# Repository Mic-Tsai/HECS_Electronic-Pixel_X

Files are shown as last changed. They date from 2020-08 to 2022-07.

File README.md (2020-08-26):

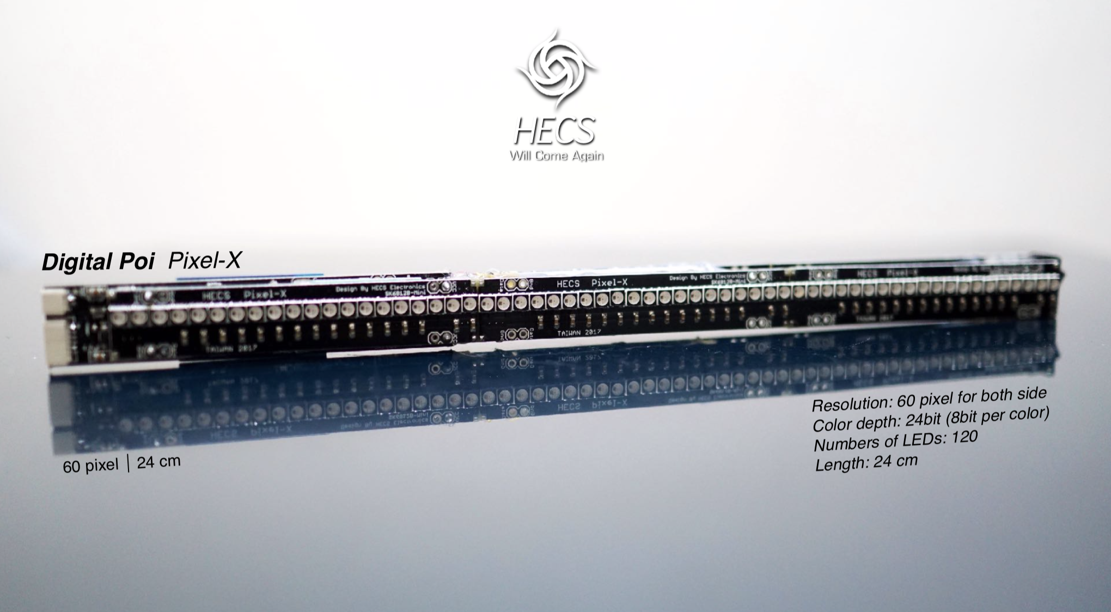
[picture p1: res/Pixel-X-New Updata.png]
*HECS Electronic | Pixel-X*


## HECS Electronic | Pixel-X
### Light Painting Equipment



2013 | HECS

We are a visual team of POI arty performers. Design and develop the light-painting equipment which contains picture & dynamic presentation. This was my college side project during 2013-2014 in KUAS (National Kaohsiung University of Applied Sciences, Taiwan).

- [Promotional Video](https://youtu.be/c2NhDoxItCM)

**2017 | Pixel-X**

  **Re-engineering hardware part, split the core as controller and display, purpose to minimum PCB after-assemble space. LEDs used the improved version SK6812B-3535 (package) from WS2812B-5050, got better heat radiating, the smaller dots will increase the image resolution.**

```
Arduino tool kit, and require the following material:
- MCU: ATmega328p
- Storage: SD card
- Display: SK6812B-3535
- Power source: Li-Po Battery
``` 

## 

### **About Mic**

Director of HECS, design light painting product that contains hardware layout and software programming.

- [Resume](https://drive.google.com/file/d/1NEWwNo3X4ogJMNzp6jpFyT0a6GPGhs7Q/view)
## 

### **About HECS**

Interesting how it work please refer for detail:

- [HECS ISSUU](https://issuu.com/56905554/docs/hecs_book)

- [HECS ISSUU moble device](https://issuu.com/56905554/docs/hecs-book_issuu)

- [HECS Electronics](https://drive.google.com/file/d/1tgr780FQ_Ib0JO3FdQn_M6LVbDeVmUmG/view?usp=sharing)
## 

### **About Hardware**

If you want to buy this board and are in Taiwan, please visit my shop: 

Will OPEN SOON:
* [HECS SHOP](https://www.)
* Contact me via mail (xbcke12345@gmail.com)
* If this project helping. Please generously support =)

   

## 
*HECS Electronic | Pixel-X*
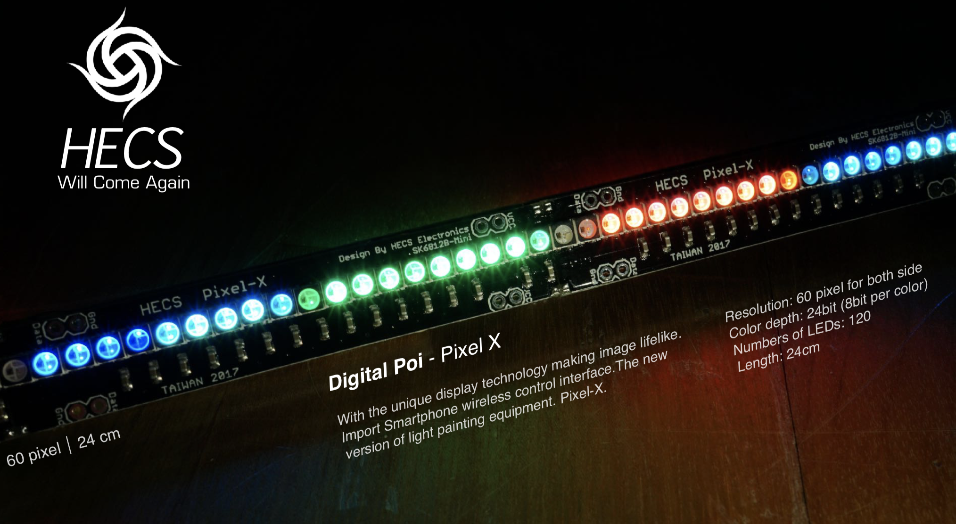
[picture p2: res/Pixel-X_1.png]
*HECS Electronic | Pixel-X*

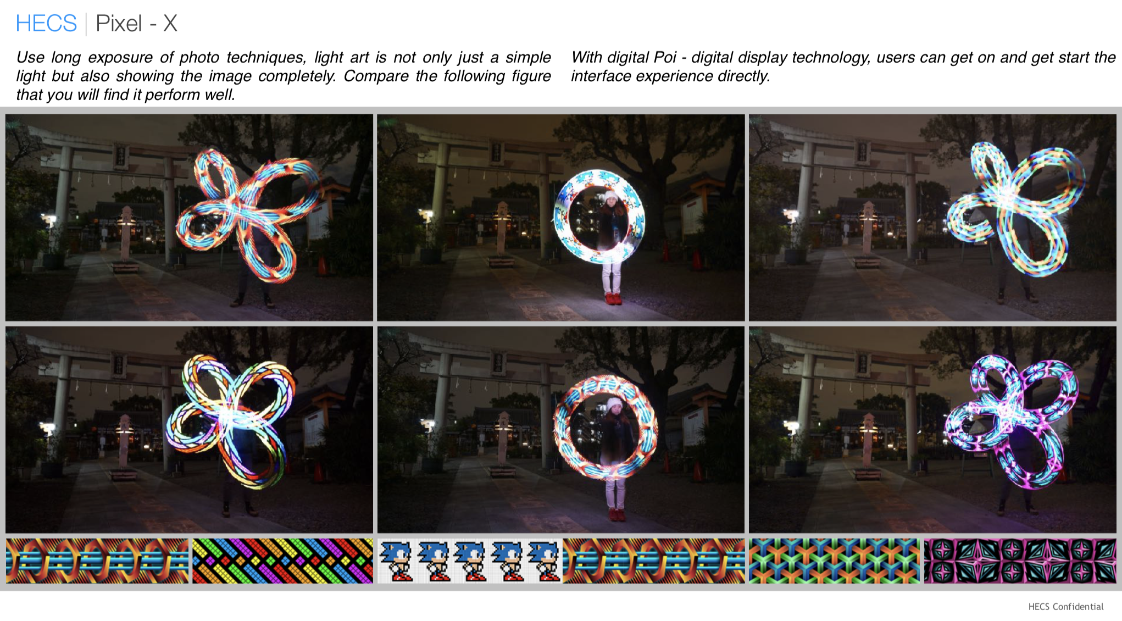
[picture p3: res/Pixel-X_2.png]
*HECS Electronic | Pixel-X*

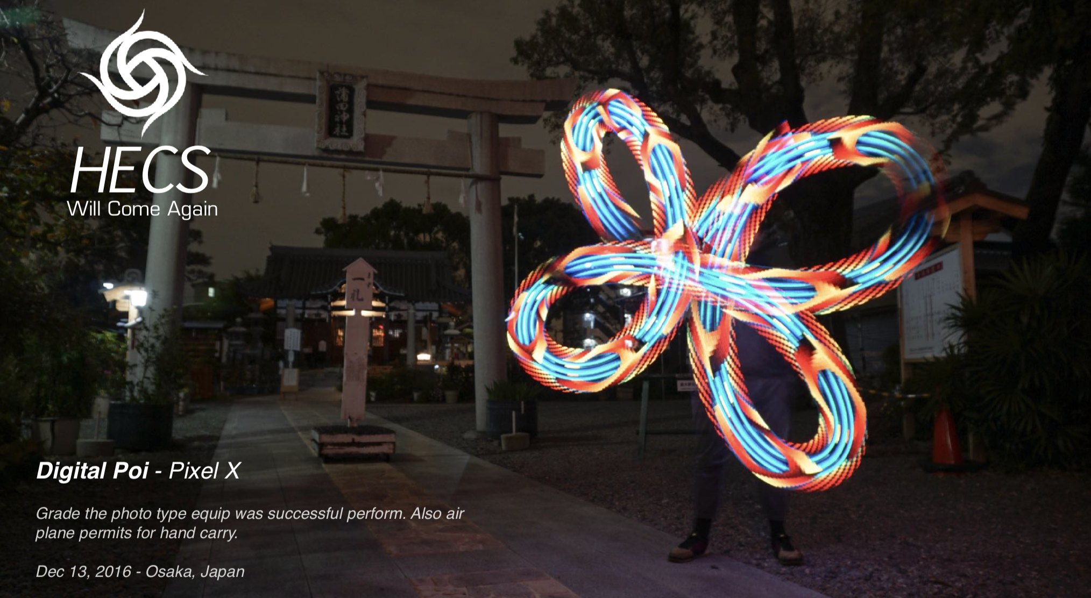
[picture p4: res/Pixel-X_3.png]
*HECS Electronic | Pixel-X*

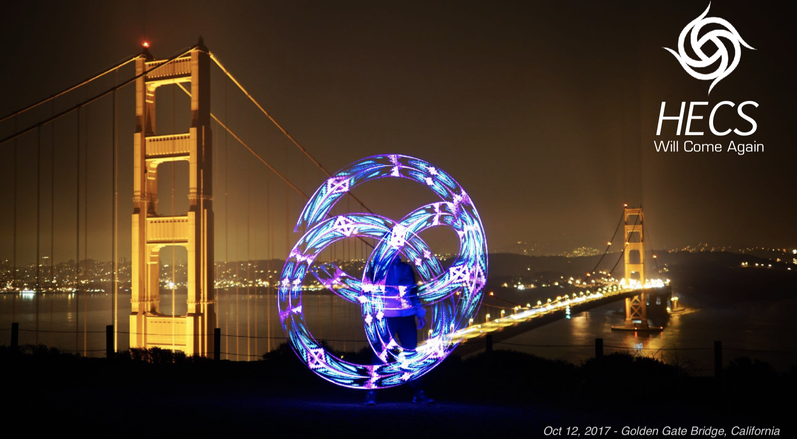
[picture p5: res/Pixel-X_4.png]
*HECS Electronic | Pixel-X*

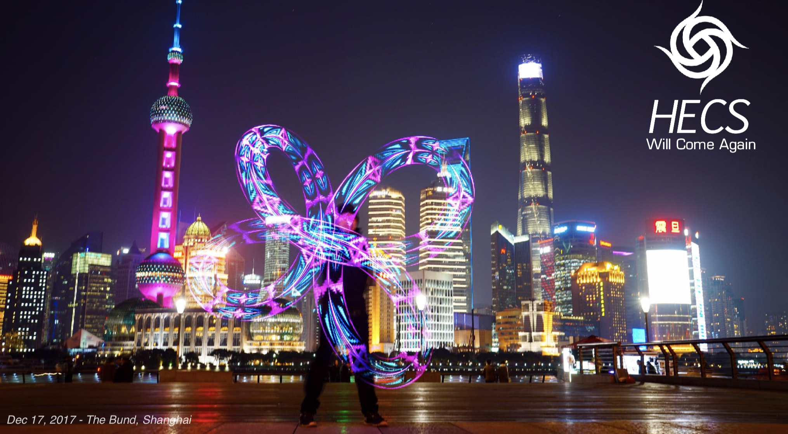
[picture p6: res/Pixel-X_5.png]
*HECS Electronic | Pixel-X*

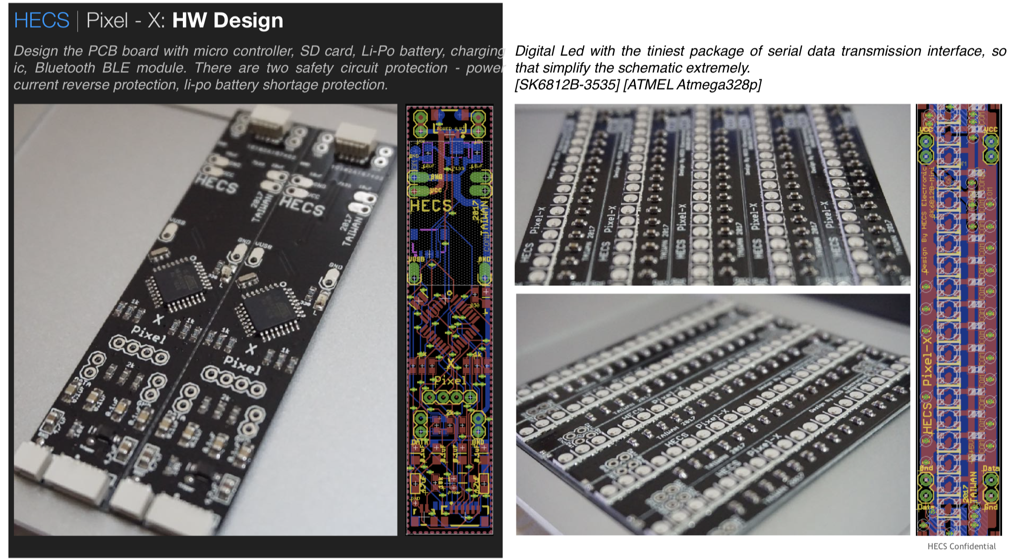
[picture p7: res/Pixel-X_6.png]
*HECS Electronic | Pixel-X*

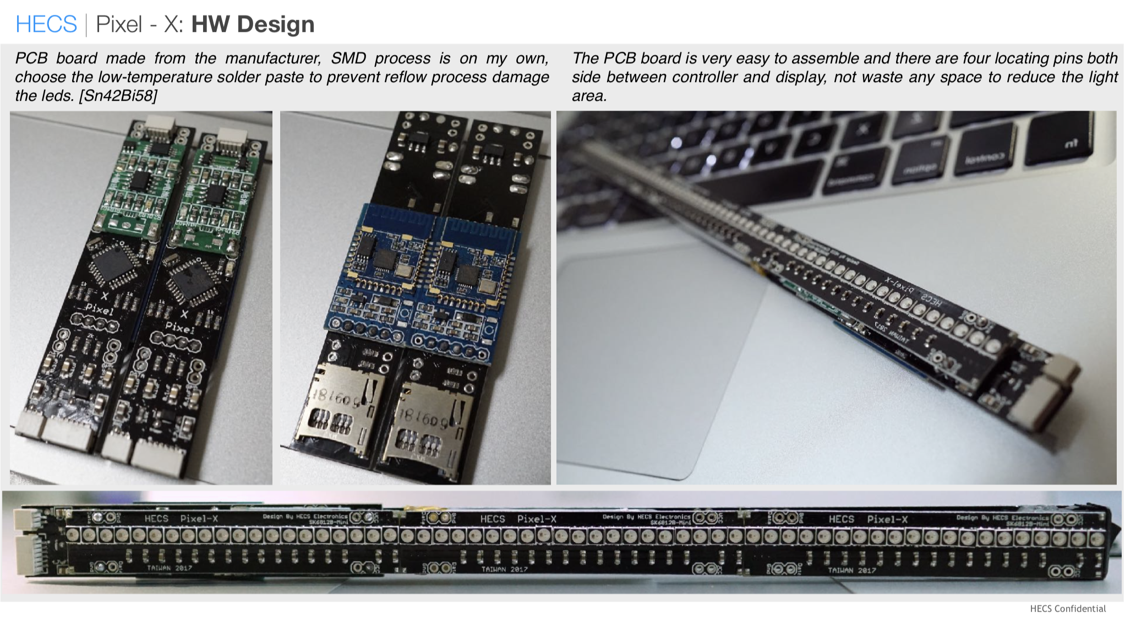
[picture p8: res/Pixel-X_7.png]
*HECS Electronic | Pixel-X*

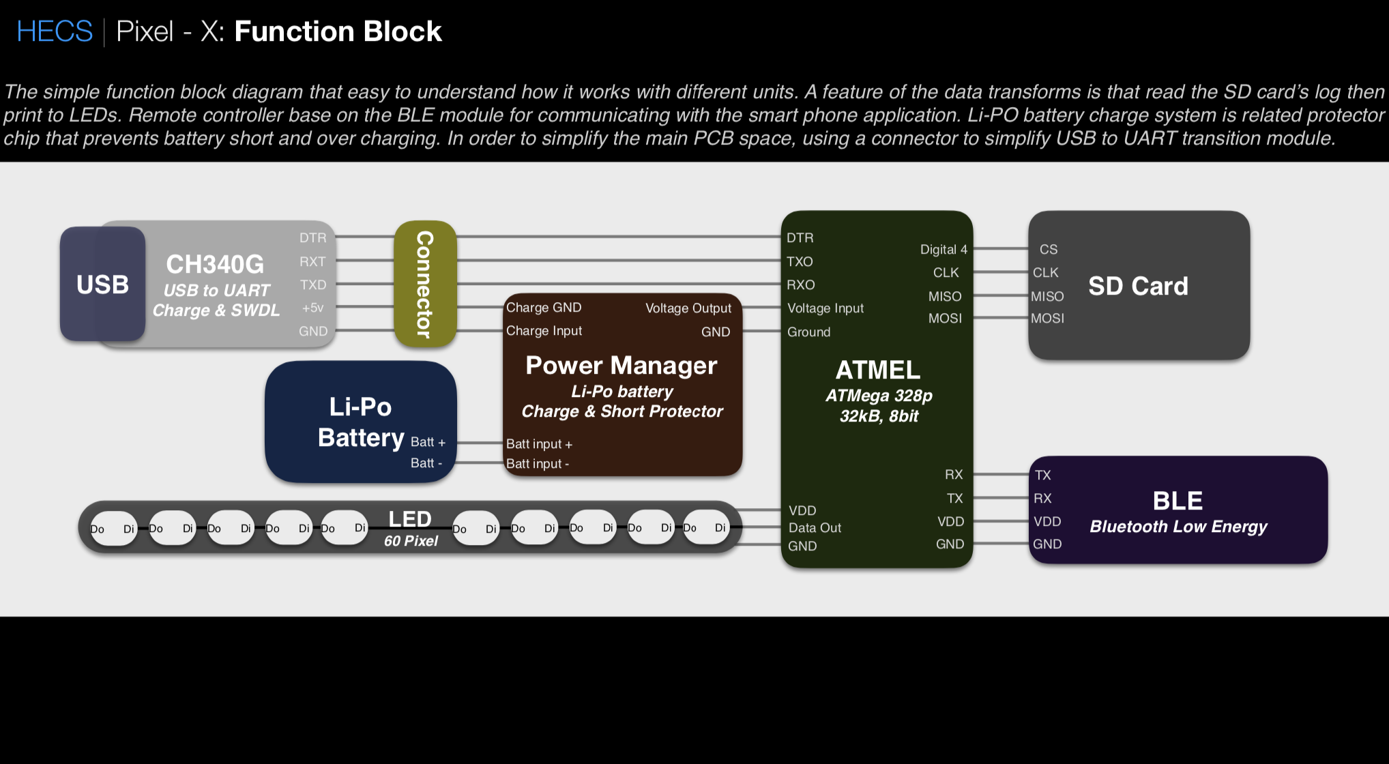
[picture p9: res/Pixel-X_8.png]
*HECS Electronic | Pixel-X*

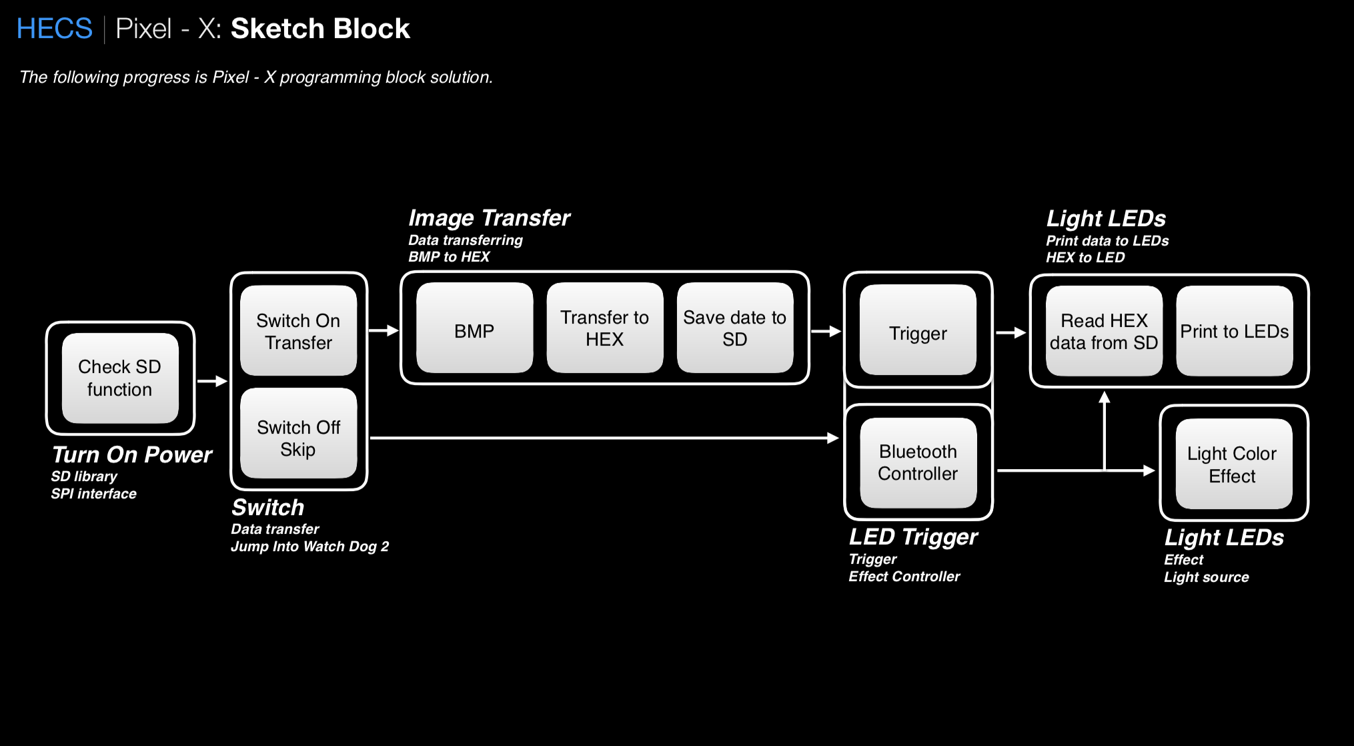
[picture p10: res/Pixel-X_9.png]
*HECS Electronic | Pixel-X*

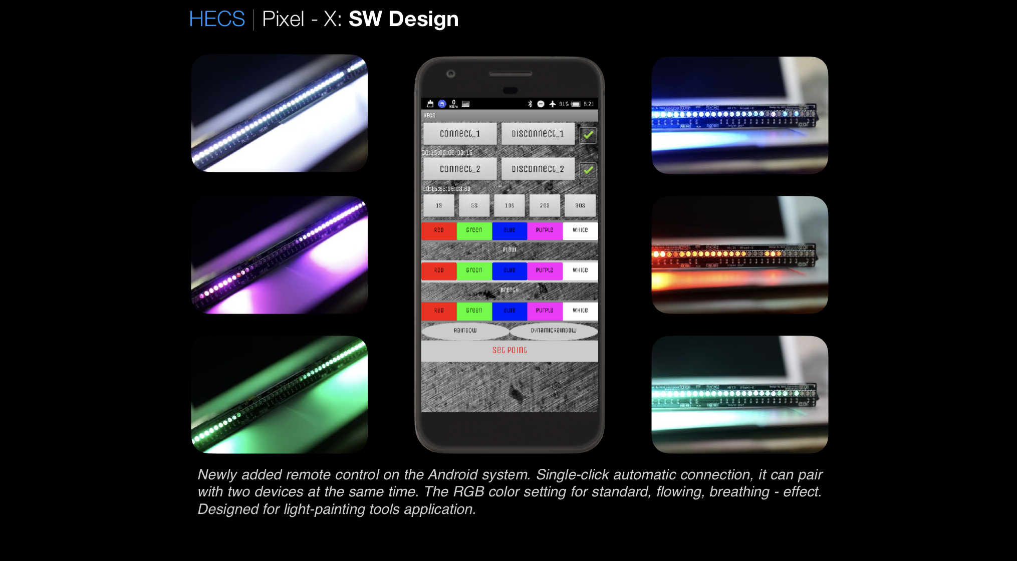
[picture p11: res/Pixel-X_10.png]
*HECS Electronic | Pixel-X*

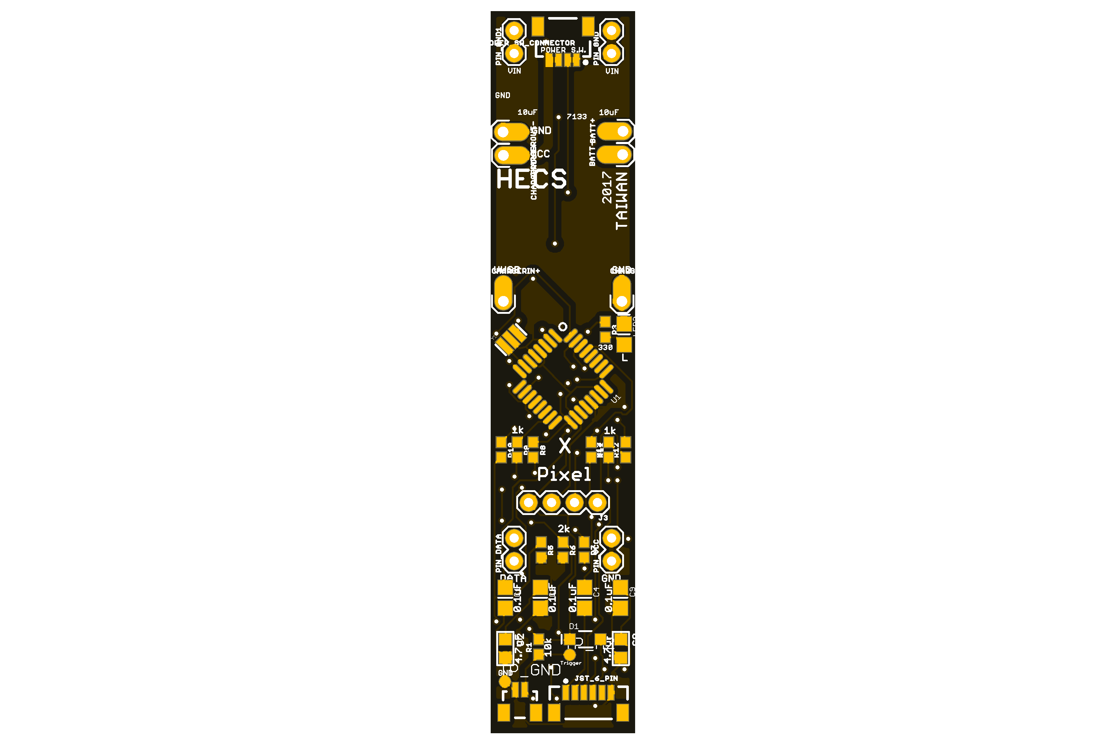
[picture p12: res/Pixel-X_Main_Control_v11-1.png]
*HECS Electronic | Pixel-X*

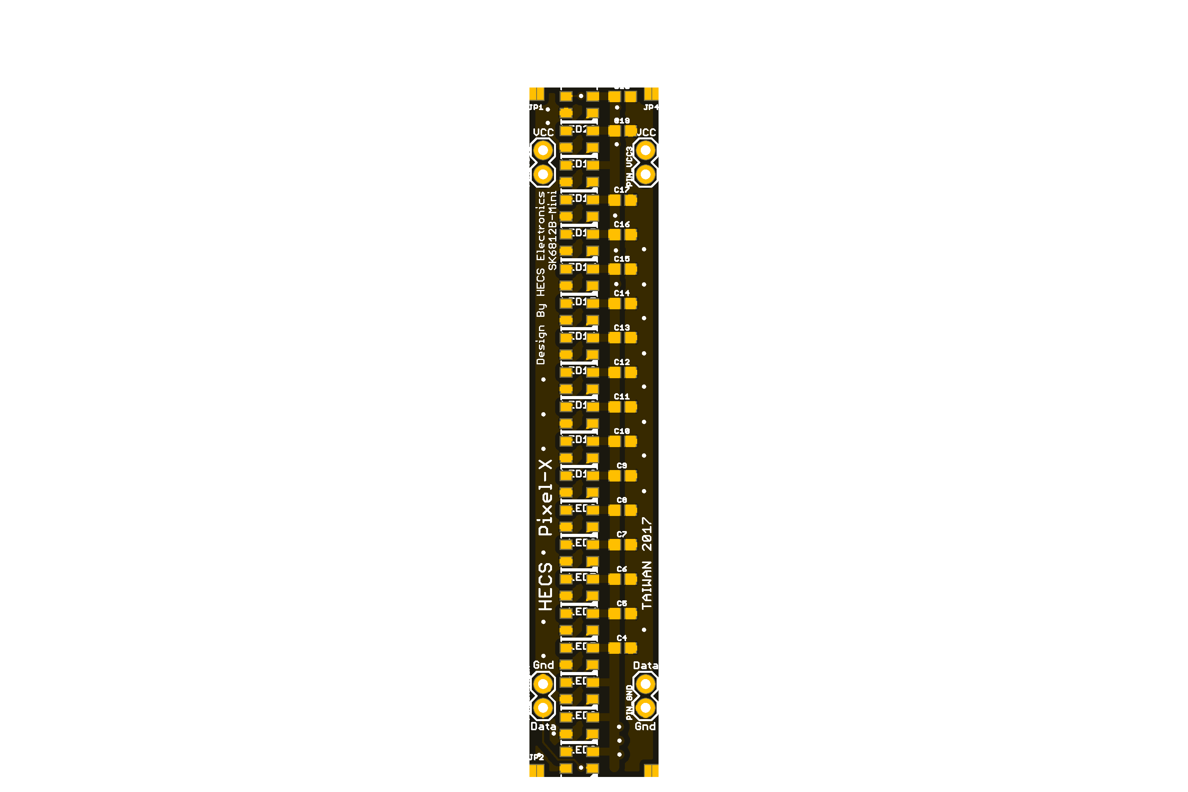
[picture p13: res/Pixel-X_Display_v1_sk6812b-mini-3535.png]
*HECS Electronic | Pixel-X*

## 

>### License Information
>>This product is open source! Both, our hardware and software are open source and licensed under the following:
>>#### Hardware
>>>All hardware is released under [Creative Commons Share-alike 4.0 International](http://creativecommons.org/licenses/by-sa/4.0/).
>>#### Software 
>>>All software is released under the MIT License [http://opensource.org/licenses/MIT](http://opensource.org/licenses/MIT).
>>#### Documentation
>>>The documentation on this page is released under [Creative Commons Share-alike 4.0 International](http://creativecommons.org/licenses/by-sa/4.0/).

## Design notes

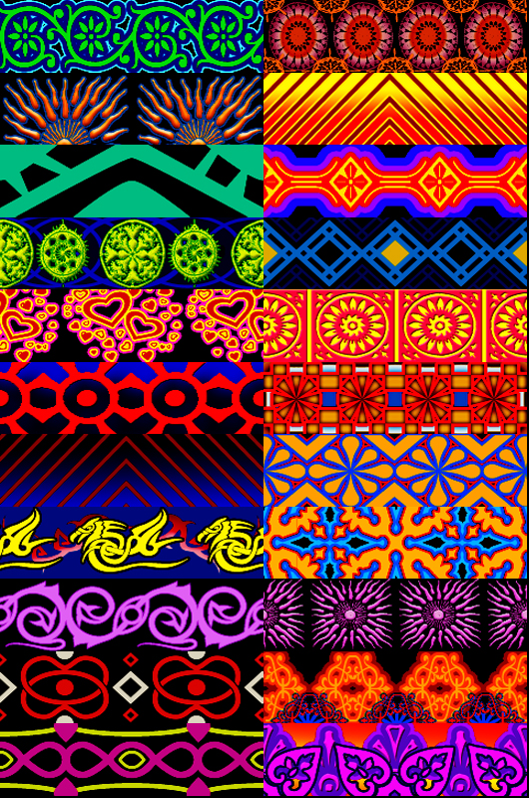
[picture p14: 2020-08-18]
Pixel-X_Image/Original/de-lux-1.jpg

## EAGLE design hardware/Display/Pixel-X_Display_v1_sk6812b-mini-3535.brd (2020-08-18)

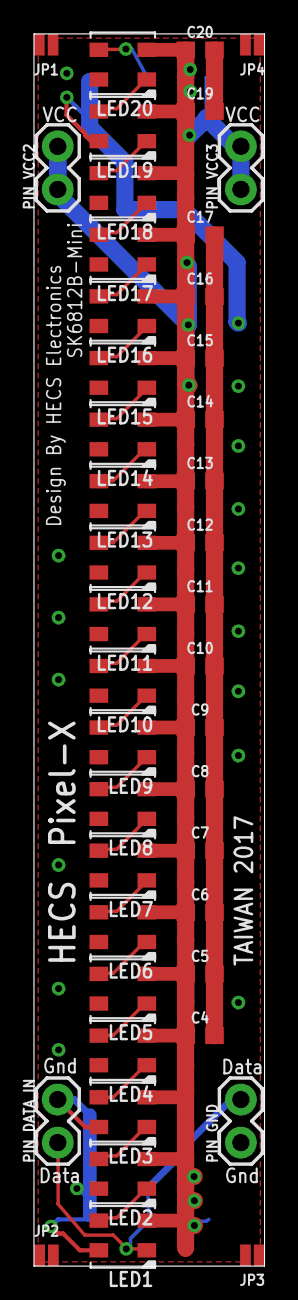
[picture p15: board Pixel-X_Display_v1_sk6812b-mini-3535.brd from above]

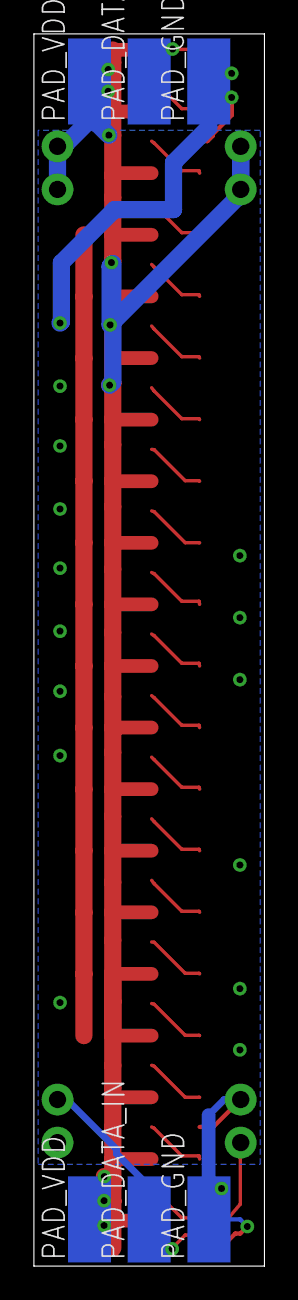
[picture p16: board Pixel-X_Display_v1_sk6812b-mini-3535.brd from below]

Board: 2 copper layers, 13.6 x 72.7 mm, 50 parts (6 on the bottom side), 23 nets.

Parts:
C4, C5, C6, C7, C8, C9, C10, C11, C12, C13, C14, C15, C16, C17, C19, C20: 0.1uF; 0603
JP1, JP2, JP3, JP4: JUMPER-SMT_2_NO_NO-SILK; SMT-JUMPER_2_NO_NO-SILK
LED1, LED2, LED3, LED4, LED5, LED6, LED7, LED8, LED9, LED10, LED11, LED12, LED13, LED14, LED15, LED16, LED17, LED18, LED19, LED20: WS2812B3535; LED3535
PAD_DATA_IN: SMD2,54-5,08
PAD_DATA_OUT: SMD2,54-5,08
PAD_GND, PAD_GND1: SMD2,54-5,08
PAD_VDD, PAD_VDD1: SMD2,54-5,08
PIN_DATA_IN: 1X02
PIN_GND: 1X02
PIN_VCC2, PIN_VCC3: 1X02

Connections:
+5V: C4.1, C5.1, C6.1, C7.1, C8.1, C9.1, C10.1, C11.1, C12.1, C13.1, C14.1, C15.1, C16.1, C17.1, C19.1, C20.1, LED1.2, LED2.2, LED3.2, LED4.2, LED5.2, LED6.2, LED7.2, LED8.2, LED9.2, LED10.2, LED11.2, LED12.2, LED13.2, LED14.2, LED15.2, LED16.2, LED17.2, LED18.2, LED19.2, LED20.2, PAD_VDD.1, PAD_VDD1.1, PIN_VCC2.1, PIN_VCC2.2, PIN_VCC3.1, PIN_VCC3.2
COM: C4.2, C5.2, C6.2, C7.2, C8.2, C9.2, C10.2, C11.2, C12.2, C13.2, C14.2, C15.2, C16.2, C17.2, C19.2, C20.2, LED1.4, LED2.4, LED3.4, LED4.4, LED5.4, LED6.4, LED7.4, LED8.4, LED9.4, LED10.4, LED11.4, LED12.4, LED13.4, LED14.4, LED15.4, LED16.4, LED17.4, LED18.4, LED19.4, LED20.4, PAD_GND.1, PAD_GND1.1, PIN_DATA_IN.2, PIN_GND.1
unnamed: LED1.1, PAD_DATA_IN.1, PIN_DATA_IN.1, PIN_GND.2
unnamed: LED1.3, LED2.1
unnamed: LED2.3, LED3.1
unnamed: LED3.3, LED4.1
unnamed: LED4.3, LED5.1
unnamed: LED5.3, LED6.1
unnamed: LED6.3, LED7.1
unnamed: LED7.3, LED8.1
unnamed: LED8.3, LED9.1
unnamed: LED9.3, LED10.1
unnamed: LED10.3, LED11.1
unnamed: LED11.3, LED12.1
unnamed: LED12.3, LED13.1
unnamed: LED13.3, LED14.1
unnamed: LED15.3, LED16.1
unnamed: LED16.3, LED17.1
unnamed: LED17.3, LED18.1
unnamed: LED18.3, LED19.1
unnamed: LED19.3, LED20.1
unnamed: LED14.3, LED15.1
unnamed: LED20.3, PAD_DATA_OUT.1

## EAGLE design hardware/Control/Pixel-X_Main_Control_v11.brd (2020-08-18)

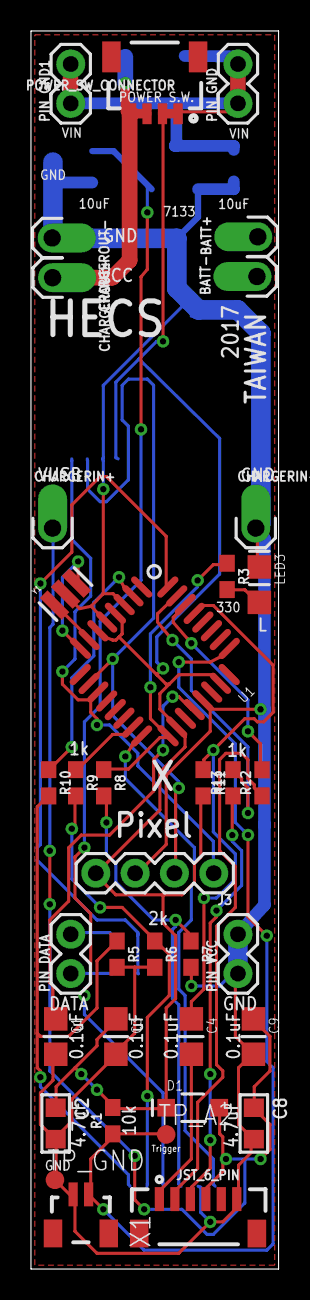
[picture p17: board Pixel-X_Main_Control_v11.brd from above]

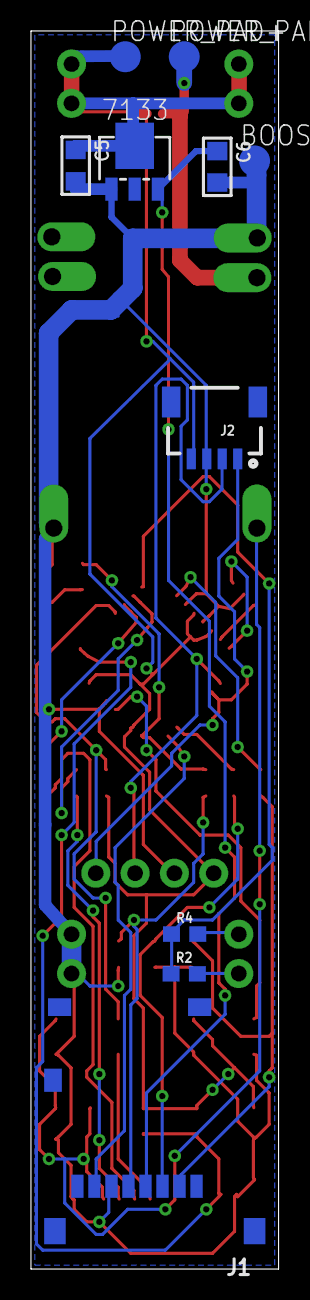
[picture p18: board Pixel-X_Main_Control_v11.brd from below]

Board: 2 copper layers, 16.0 x 80.0 mm, 47 parts (10 on the bottom side), 28 nets.

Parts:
7133: L78LXXCU/BU; SOT89
BATT+: 1X01_OFFSET
BATT-: 1X01_OFFSET
BOOSTOUT-: TPSQTP20R; TP20R
C1, C3, C4, C9: 0.1uF; CAP0805-NP
C2, C8: 4.7uF; C0805
C5, C6: 10uF; C0805
CHARGERIN+: 1X01_OFFSET
CHARGERIN-: 1X01_OFFSET
CHARGEROUT+: 1X01_OFFSET
CHARGEROUT-: 1X01_OFFSET
D1: MBR0520; SOD-123
J1: MICROSD_MOLEX_5025700893; 5025700893
J2: 1X04_1MM_RA
J3: 1X04
JST_6_PIN: JST_6_PIN_VERTICAL; JST-6-SMD-VERT-1.0MM
LED3: L_AMBER; LED0805
PIN_DATA: 1X02
PIN_GND, PIN_GND1: 1X02
PIN_VCC: 1X02
POWER_PAD+: TPSQTP20R; TP20R
POWER_PAD-: TPSQTP20R; TP20R
POWER_SW_CONNECTOR: 1X04_1MM_RA
R1: 10k; 0603
R2, R4: 120; 0603
R3: 330; 0603
R5, R6, R7: 2k; 0603
R8, R9, R10, R11, R12, R13: 1k; 0603
TP_A2: TPTP12R; TP12R
TP_GND: TPTP12R; TP12R
U1: ATMEGA328; QFP032
X1: BM02B-SRSS-TB
Y1: 16MHz; RESONATOR

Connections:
3V3OUT: 7133.3, C6.1, J1.P$4
+5V: 7133.4, C2.1, C3.1, C5.1, D1.1, J2.4, J3.4, PIN_GND.1, PIN_GND.2, PIN_GND1.1, PIN_GND1.2, POWER_PAD+.TP, POWER_SW_CONNECTOR.1, POWER_SW_CONNECTOR.2, R1.2, R11.2, U1.4, U1.6, U1.18, U1.23
A2: R1.1, TP_A2.TP, U1.25, X1.2
AREF: C1.1, U1.20
COM: 7133.1, BOOSTOUT-.TP, C1.2, C2.2, C3.2, C5.2, C6.2, C8.2, C9.2, CHARGERIN-.1, CHARGEROUT-.1, J1.P$6, J2.3, J3.3, JST_6_PIN.6, LED3.1, PIN_VCC.1, PIN_VCC.2, R5.2, R6.2, R7.2, TP_GND.TP, U1.3, U1.5, U1.21, X1.1, Y1.2
D0/RX: R12.2, U1.30
D1/TX: R13.2, U1.31
D2: R2.1, R4.1, U1.32
D4: R10.1, U1.2
D6: J2.2, J3.2, U1.10
D7: J2.1, J3.1, U1.11
D11/MOSI: R9.1, U1.15
D12/MISO: J1.P$7, U1.16
D13/SCK: R3.1, R8.1, U1.17
DTR: C4.1, R11.1, U1.29
unnamed: U1.8, Y1.3
unnamed: U1.7, Y1.1
unnamed: PIN_DATA.2, R4.2
unnamed: PIN_DATA.1, R2.2
unnamed: C4.2, JST_6_PIN.1
unnamed: LED3.2, R3.2
unnamed: J1.P$2, R5.1, R10.2
unnamed: J1.P$3, R6.1, R9.2
unnamed: J1.P$5, R7.1, R8.2
unnamed: CHARGEROUT+.1, POWER_PAD-.TP, POWER_SW_CONNECTOR.3, POWER_SW_CONNECTOR.4
RX: JST_6_PIN.2, R12.1
TX: JST_6_PIN.3, R13.1
VUSB: C8.1, C9.1, CHARGERIN+.1, D1.2, JST_6_PIN.4

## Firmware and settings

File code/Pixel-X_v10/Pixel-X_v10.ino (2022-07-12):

// ###################################################################################
// # Project: Pixel-X v9
// # Engineer:  Mic.Tsai
// # Date:  2 July 2022
// # Objective: Dev.board
// # Usage: ATmega328p
// ###################################################################################

/////////////////////////////////
// Important:
// Only Arduino 1.0.6 can sketch this code
// Check cycle time
/////////////////////////////////

// Requires SdFat library for Arduino:
// http://code.google.com/p/sdfatlib/

// Requires NeoPixel library:
// https://github.com/adafruit/Adafruit_NeoPixel

// This project is base on NeoPixel Painter from Adafruit 
// If you need detail building process please visit here (step by step)
// https://learn.adafruit.com/neopixel-painter?view=all
// https://github.com/adafruit/NeoPixel_Painter
// ###################################################################################

#include <SdFat.h>
#include <avr/pgmspace.h>
#include "./gamma.h"

#include <Adafruit_NeoPixel.h>
#include "WS2812_Definitions.h"
#include <SoftwareSerial.h>
SoftwareSerial BT(6,7);
char val;
byte i;
byte j;
#define PIN 2
#define LED_COUNT 60
Adafruit_NeoPixel leds = Adafruit_NeoPixel(LED_COUNT, PIN, NEO_GRB + NEO_KHZ800);

// CONFIGURABLE STUFF --------------------------------------------------------

//************************************************************
//************************************************************
#define CURRENT_MAX   1800   //Brightness-setting(500-1800) Max current from power supply (mA)
//************************************************************
//************************************************************

#define N_LEDS        60    // Max value is 170 (fits one SD card block)
#define CARD_SELECT    4    // SD card select pin (some shields use #4, not 10)
#define LED_PIN        2    // NeoPixels connect here
#define SPEED         A0    // Speed-setting dial
int BRIGHTNESS =      255;  // Brightness-setting dial /no function
#define TRIGGER       A2    // Playback trigger pin
//#define STAR          A2
//************************************************************
//************************************************************

  int STAR = LOW;               // Set LOW go direct display
                            // Set HIGH need button trigger
//************************************************************
//************************************************************    
                        
// NON-CONFIGURABLE STUFF ----------------------------------------------------

#define OVERHEAD 150 // Extra microseconds for loop processing, etc.

uint8_t           sdBuf[512],  // One SD block (also for NeoPixel color data)
                  pinMask;     // NeoPixel pin bitmask
uint16_t          maxLPS,      // Max playback lines/sec
                  nFrames = 0, // Total # of image files
                  frame   = 0; // Current image # being painted
uint32_t          firstBlock,  // First block # in temp working file
                  nBlocks;     // Number of blocks in file
Sd2Card           card;        // SD card global instance (only one)
SdVolume          volume;      // Filesystem global instance (only one)
SdFile            root;        // Root directory (only one)
volatile uint8_t *port;        // NeoPixel PORT register

// INITIALIZATION ------------------------------------------------------------

void setup() {
  
  BT.begin(9600);
  leds.begin();
  clearLEDs();
  leds.show();
 
  uint8_t  b, startupTrigger, minBrightness;
  char     infile[13], outfile[13];
  boolean  found;
  uint16_t i, n;
  SdFile   tmp;
  uint32_t lastBlock;

  pinMode(13, OUTPUT);
  digitalWrite(TRIGGER, HIGH);           // Enable pullup on trigger button
  
//************************************************************
//************************************************************

  startupTrigger = HIGH; // Set LOW go direct to transfer bmp image process
                        // Set HIGH  --> Skip
                        
//************************************************************
//************************************************************


  
  Serial.begin(9600);
  pinMode(LED_PIN, OUTPUT);              // Enable NeoPixel output
  digitalWrite(LED_PIN, LOW);            // Default logic state = low
  port    = portOutputRegister(digitalPinToPort(LED_PIN));
  pinMask = digitalPinToBitMask(LED_PIN);
  memset(sdBuf, 0, N_LEDS * 3);          // Clear LED buffer
  show();                                // Init LEDs to 'off' state
#ifdef ENCODERSTEPS
  digitalWrite(5, HIGH);                 // Enable pullup on encoder pin
#endif

  Serial.print(F("Initializing SD card..."));
  if(!card.init(SPI_FULL_SPEED, CARD_SELECT)) {
    error(F("failed. Things to check:\n"
            "* is a card is inserted?\n"
            "* Is your wiring correct?\n"
            "* did you edit CARD_SELECT to match the SD shield or module?"));
  }
  Serial.println(F("OK"));

  if(!volume.init(&card)) {
    error(F("Could not find FAT16/FAT32 partition.\n"
            "Make sure the card is formatted."));
  }
  root.openRoot(&volume);

  // This simple application always reads the files 'frameNNN.bmp' in
  // the root directory; there's no file selection mechanism or UI.

  // If button is held at startup, the processing step is skipped, just
  // goes right to playback of the prior converted file(s) (if present).
  if(startupTrigger == LOW) { // button pressed

    // Two passes are made over the input images.  First pass counts the
    // files and estimates the max brightness level that the power supply
    // can sustain...
    minBrightness = 255;
    do {
      sprintf(infile, "frame%03d.bmp", nFrames);
      b = 255;
      if(found = bmpProcess(root, infile, NULL, &b)) { // b modified to safe max
        nFrames++;
        if(b < minBrightness) minBrightness = b;
      }
    } while(found && (nFrames < 1000));

    Serial.print(nFrames);
    Serial.print(" frames\nbrightness = ");
    Serial.println(minBrightness);

    // Read dial, setting brightness between 1 (almost but not quite off)
    // and the previously-estimated safe max.
    b = map(BRIGHTNESS, 0, 1023, 1, minBrightness);
  
    // Second pass now applies brightness adjustment while converting
    // the image(s) from BMP to a raw representation of NeoPixel data
    // (this outputs the file(s) 'frameNNN.tmp' -- any existing file
    // by that name will simply be clobbered, IT DOES NOT ASK).
    for(i=0; i<nFrames; i++) {
      sprintf(infile , "frame%03d.bmp", i);
      sprintf(outfile, "frame%03d.tmp", i);
      b = minBrightness;
      bmpProcess(root, infile, outfile, &b);
    }
    //while(digitalRead(TRIGGER) == HIGH); // Wait for button release

  } else { // Button not held -- use existing data

    do { // Scan for files to get nFrames
      sprintf(infile, "frame%03d.tmp", nFrames);
      if(found = tmp.open(&root, infile, O_RDONLY)) {
        if(tmp.contiguousRange(&firstBlock, &lastBlock)) {
          nFrames++;
        }
        tmp.close();
      }
    } while(found);

  } // end startupTrigger test

#ifdef ENCODERSTEPS
  // To use a rotary encoder rather than timer, connect one output
  // of encoder to T1 pin (digital pin 5 on Arduino Uno).  A small
  // capacitor across the encoder pins may help for debouncing.
  TCCR1A = _BV(WGM11) | _BV(WGM10);
  TCCR1B = _BV(WGM13) | _BV(WGM12) | _BV(CS12) | _BV(CS11);
#else
  // Prepare for playback from file; make a full read pass through the
  // file to estimate block read time (+5% margin) and max playback
  // lines/sec.  Not all SD cards perform the same.  This makes sure a
  // reasonable speed limit is used.
  for(i=0; i<nFrames; i++) { // Scan all files
    sprintf(infile, "frame%03d.tmp", i);
    tmp.open(&root, infile, O_RDONLY);
    tmp.contiguousRange(&firstBlock, &lastBlock);
    nBlocks = tmp.fileSize() / 512;
    tmp.close();
    n = (uint16_t)(1000000L /                         // 1 uSec /
      (((benchmark(firstBlock, nBlocks) * 21) / 20) + // time + 5% +
       (N_LEDS * 30L) + OVERHEAD));                   // 30 uSec/pixel
         Serial.print(F("N: "));
         Serial.println(n);
    if(n > maxLPS) maxLPS = n;
  }
  if(maxLPS > 300) maxLPS = 326; // NeoPixel PWM rate is ~400 Hz //change 326
  Serial.print(F("Max lines/sec: "));
  Serial.println(maxLPS);

  // Set up Timer1 for 64:1 prescale (250 KHz clock source),
  // fast PWM mode, no PWM out.
  TCCR1A = _BV(WGM11) | _BV(WGM10);
  TCCR1B = _BV(WGM13) | _BV(WGM12) | _BV(CS11) | _BV(CS10);
  // Timer1 interrupt is not used; instead, overflow bit is tightly
  // polled.  Very infrequently a block read may inexplicably take longer
  // than normal...using an interrupt, the code would clobber itself.
  // By polling instead, worst case is just a minor glitch where the
  // corresponding row will be a little thicker than normal.
#endif

  // Timer0 interrupt is disabled for smoother playback.
  // This means delay(), millis(), etc. won't work after this.
  TIMSK0 = 0;

  ReadyFlowWhite(1);
}

// Startup error handler; doesn't return, doesn't run loop(), just stops.
static void error(const __FlashStringHelper *ptr) {
    Serial.println(ptr); // Show message    
    for(;;);             // and hang
}


// PLAYBACK LOOP ------------------------------------------------------------------------------------------------------------------------

void loop() 
{
  if(STAR == LOW)
  {
    Setpoint();  
  }
  if(BT.available())
  {
     val = BT.read();
     switch (val)
      {
        case 'm':      
          Setpoint();          
          break;
        case '1':
          bmpDraw(294); // 1s
          break;
        case '2':
          bmpDraw(1470); //  5s
          break;
        case '3':
          bmpDraw(3078); //  10s
          break;
        case '4':
          bmpDraw(6468); //  20s
          break;
        case '5':
          bmpDraw(9408);  //30s
          break;
        case 'a':
          FlowRed(10);
          break;
        case 's':
          FlowGreen(10);
          break;
        case 'd':
          FlowBlue(10);
          break;
        case 'f':
          FlowPurple(10);
          break;
        case 'g':
          FlowWhite(10);
          break;
        case 'o':
          Rainbow(15);
          break;  
        case 'p':
          DynamicRainbow(10); 
          break;
        case 'q':
          Red(); 
          break;
        case 'w':
          Green(); 
          break;
        case 'e':
          Blue(); 
          break;
        case 'r':
          Purple(); 
          break;
        case 't':
          White(); 
          break;
        case 'z':
          BreatheRed(5); 
          break;
        case 'x':
          BreatheGreen(5); 
          break;
        case 'c':
          BreatheBlue(5); 
          break;
        case 'v':
          BreathePurple(5); 
          break;
        case 'b':
          BreatheWhite(5); 
          break;
      }
  }
}

// PLAYBACK LOOP ------------------------------------------------------------------------------------------------------------------------



void bmpDraw(unsigned long time) {
 
  uint32_t block    = 0;     // Current block # within file
  boolean  stopFlag = false; // If set, stop playback loop
  uint32_t lastBlock;
  char     infile[13];
  SdFile   tmp;

  // Get existing contiguous tempfile info
  sprintf(infile, "frame%03d.tmp", frame);
  if(!tmp.open(&root, infile, O_RDONLY)) {
    error(F("Could not open NeoPixel tempfile for input"));
  }
  if(!tmp.contiguousRange(&firstBlock, &lastBlock)) {
    error(F("NeoPixel tempfile is not contiguous"));
  }
  // Number of blocks needs to be calculated from file size, not the
  // range values.  The contiguous file creation and range functions
  // work on cluster boundaries, not necessarily the actual file size.
  nBlocks = tmp.fileSize() / 512;

  tmp.close(); // File handle is no longer accessed, just block reads

  // Stage first block, but don't display yet -- the loop below
  // does that only when Timer1 overflows.
  card.readBlock(firstBlock, sdBuf);
  // readBlock is used rather than readStart/readData/readEnd as
  // the duration between block reads may exceed the SD timeout.

//  while(digitalRead(TRIGGER) == HIGH);   // Wait for trigger button

#ifdef ENCODERSTEPS
  // Set up for rotary encoder
  TCNT1 = 0;
  OCR1A = ENCODERSTEPS;
#else
  // Set up timer based on dial input
  uint32_t linesPerSec = map(analogRead(SPEED), 0, 1023, 10, maxLPS);
  //Serial.print(F("linesPerSec: "));
  //Serial.println(linesPerSec);
  //Serial.print(F("OCR1A: "));
  OCR1A = (F_CPU / 64) / linesPerSec;          // Timer1 interval
  //Serial.println(OCR1A);
#endif

//  for(;;) 
  for(int x =0 ; x<time ; x++ ) 
  {
    while(!(TIFR1 & _BV(TOV1)));               // Wait for Timer1 overflow
    TIFR1 |= _BV(TOV1);                        // Clear overflow bit

    show();                                    // Display current line
    if(stopFlag) break;                        // Break when done

    if(++block >= nBlocks) 
    {                   // Past last block?
      /*
      if(digitalRead(TRIGGER) == HIGH)
      {       // Trigger released?
        memset(sdBuf, 0, N_LEDS * 3);          // LEDs off on next pass
        stopFlag = true;                       // Stop playback on next pass
        continue;
      }         // Else trigger still held
      */
      block = 0;                               // Loop back to start
    }
    card.readBlock(block + firstBlock, sdBuf); // Load next pixel row
  }
  if(++frame >= nFrames) frame = 0;
}

// BMP->NEOPIXEL FILE CONVERSION ---------------------------------------------

#define BMP_BLUE  0 // BMP and NeoPixels have R/G/B color
#define BMP_GREEN 1 // components in different orders.
#define BMP_RED   2 // (BMP = BGR, Neo = GRB)
#define NEO_GREEN 0
#define NEO_RED   1
#define NEO_BLUE  2

// Convert file from 24-bit Windows BMP format to raw NeoPixel datastream.
// Conversion is bottom-to-top (see notes below)...for horizontal light
// painting, the image is NOT rotated here (the per-pixel file seeking this
// requires takes FOREVER on the Arduino).  Instead, such images should be
// rotated counterclockwise (in Photoshop or other editor) prior to moving
// to SD card.  As currently written, both the input and output files need
// to be in the same directory.  Brightness is set during conversion; there
// aren't enough cycles to do this in realtime during playback.  To change
// brightness, re-process image file using new brightness value.
boolean bmpProcess(
  SdFile  &path,
  char    *inName,
  char    *outName,
  uint8_t *brightness) {

  SdFile    inFile,              // Windows BMP file for input
            outFile;             // NeoPixel temp file for output
  boolean   ok        = false,   // 'true' on valid BMP & output file
            flip      = false;   // 'true' if image stored top-to-bottom
  int       bmpWidth,            // BMP width in pixels
            bmpHeight,           // BMP height in pixels
            bmpStartCol,         // First BMP column to process (crop/center)
            columns,             // Number of columns to process (crop/center)
            row,                 // Current image row (Y)
            column;              // and column (X)
  uint8_t  *ditherRow,           // 16-element dither array for current row
            pixel[3],            // For reordering color data, BGR to GRB
            b = 0,               // 1 + *brightness
            d,                   // Dither value for row/column
            color,               // Color component index (R/G/B)
            raw,                 // 'Raw' R/G/B color value
            corr,                // Gamma-corrected R/G/B
           *ledPtr,              // Pointer into sdBuf (output)
           *ledStartPtr;         // First LED column to process (crop/center)
  uint16_t  b16;                 // 16-bit dup of b
  uint32_t  bmpImageoffset,      // Start of image data in BMP file
            lineMax   = 0L,      // Cumulative brightness of brightest line
            rowSize,             // BMP row size (bytes) w/32-bit alignment
            sum,                 // Sum of pixels in row
            startTime = millis();

  if(brightness)           b = 1 + *brightness; // Wraps around, fun with maths
  else if(NULL == outName) return false; // MUST pass brightness for power est.

  Serial.print(F("Reading file '"));
  Serial.print(inName);
  Serial.print(F("'..."));
  if(!inFile.open(&path, inName, O_RDONLY)) {
    Serial.println(F("error"));
    return false;
  }

  if(inFile.read(sdBuf, 34)             &&    // Load header
    (*(uint16_t *)&sdBuf[ 0] == 0x4D42) &&    // BMP signature
    (*(uint16_t *)&sdBuf[26] == 1)      &&    // Planes: must be 1
    (*(uint16_t *)&sdBuf[28] == 24)     &&    // Bits per pixel: must be 24
    (*(uint32_t *)&sdBuf[30] == 0)) {         // Compression: must be 0 (none)
    // Supported BMP format -- proceed!
    bmpImageoffset = *(uint32_t *)&sdBuf[10]; // Start of image data
    bmpWidth       = *(uint32_t *)&sdBuf[18]; // Image dimensions
    bmpHeight      = *(uint32_t *)&sdBuf[22];
    // That's some nonportable, endian-dependent code right there.

    Serial.print(bmpWidth);
    Serial.write('x');
    Serial.print(bmpHeight);
    Serial.println(F(" pixels"));

    if(outName) { // Doing conversion?  Need outFile.
      // Delete existing outFile file (if any)
      (void)SdFile::remove(&path, outName);
      Serial.print(F("Creating contiguous file..."));
      // NeoPixel working file is always 512 bytes (one SD block) per row
      if(outFile.createContiguous(&path, outName, 512L * bmpHeight)) {
        uint32_t lastBlock;
        outFile.contiguousRange(&firstBlock, &lastBlock);
        // Once we have the first block index, the file handle
        // is no longer needed -- raw block writes are used.
        outFile.close();
        nBlocks = bmpHeight; // See note in setup() re: block calcs
        ok      = true;      // outFile is good; proceed
        Serial.println(F("OK"));
      } else {
        Serial.println(F("error"));
      }
    } else ok = true; // outFile not needed; proceed

    if(ok) { // Valid BMP and contig file (if needed) are ready
      Serial.print(F("Processing..."));

      rowSize = ((bmpWidth * 3) + 3) & ~3; // 32-bit line boundary
      b16     = (int)b;

      if(bmpHeight < 0) {       // If bmpHeight is negative,
        bmpHeight = -bmpHeight; // image is in top-down order.
        flip      = true;       // Rare, but happens.
      }

      if(bmpWidth >= N_LEDS) { // BMP matches LED bar width, or crop image
        bmpStartCol = (bmpWidth - N_LEDS) / 2;
        ledStartPtr = sdBuf;
        columns     = N_LEDS;
      } else {                 // Center narrow image within LED bar
        bmpStartCol = 0;
        ledStartPtr = &sdBuf[((N_LEDS - bmpWidth) / 2) * 3];
        columns     = bmpWidth;
        memset(sdBuf, 0, N_LEDS * 3); // Clear left/right pixels
      }

      for(row=0; row<bmpHeight; row++) { // For each row in image...
        Serial.write('.');
        // Image is converted from bottom to top.  This is on purpose!
        // The ground (physical ground, not the electrical kind) provides
        // a uniform point of reference for multi-frame vertical painting...
        // could then use something like a leaf switch to trigger playback,
        // lifting the light bar like making giant soap bubbles.

        // Seek to first pixel to load for this row...
        inFile.seekSet(
          bmpImageoffset + (bmpStartCol * 3) + (rowSize * (flip ?
          (bmpHeight - 1 - row) : // Image is stored top-to-bottom
          row)));                 // Image stored bottom-to-top
        if(!inFile.read(ledStartPtr, columns * 3))  // Load row
          Serial.println(F("Read error"));

        sum       = 0L;
        ditherRow = (uint8_t *)&dither[row & 0x0F]; // Dither values for row
        ledPtr    = ledStartPtr;
        for(column=0; column<columns; column++) {   // For each column...
          if(b) { // Scale brightness, reorder R/G/B
            pixel[NEO_BLUE]  = (ledPtr[BMP_BLUE]  * b16) >> 8;
            pixel[NEO_GREEN] = (ledPtr[BMP_GREEN] * b16) >> 8;
            pixel[NEO_RED]   = (ledPtr[BMP_RED]   * b16) >> 8;
          } else { // Full brightness, reorder R/G/B
            pixel[NEO_BLUE]  = ledPtr[BMP_BLUE];
            pixel[NEO_GREEN] = ledPtr[BMP_GREEN];
            pixel[NEO_RED]   = ledPtr[BMP_RED];
          }

          d = pgm_read_byte(&ditherRow[column & 0x0F]); // Dither probability
          for(color=0; color<3; color++) {              // 3 color bytes...
            raw  = pixel[color];                        // 'Raw' G/R/B
            corr = pgm_read_byte(&gamma[raw]);          // Gamma-corrected
            if(pgm_read_byte(&bump[raw]) > d) corr++;   // Dither up?
            *ledPtr++ = corr;                           // Store back in sdBuf
            sum      += corr;                           // Total brightness
          } // Next color byte
        } // Next column

        if(outName) {
          if(!card.writeBlock(firstBlock + row, (uint8_t *)sdBuf))
            Serial.println(F("Write error"));
        }
        if(sum > lineMax) lineMax = sum;

      } // Next row
      Serial.println(F("OK"));

      if(brightness) {
        lineMax = (lineMax * 20) / 255; // Est current @ ~20 mA/LED
        if(lineMax > CURRENT_MAX) {
          // Estimate suitable brightness based on CURRENT_MAX
          *brightness = (*brightness * (uint32_t)CURRENT_MAX) / lineMax;
        } // Else no recommended change
      }

      Serial.print(F("Processed in "));
      Serial.print(millis() - startTime);
      Serial.println(F(" ms"));

    } // end 'ok' check
  } else { // end BMP header check
    Serial.println(F("BMP format not recognized."));
  }
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

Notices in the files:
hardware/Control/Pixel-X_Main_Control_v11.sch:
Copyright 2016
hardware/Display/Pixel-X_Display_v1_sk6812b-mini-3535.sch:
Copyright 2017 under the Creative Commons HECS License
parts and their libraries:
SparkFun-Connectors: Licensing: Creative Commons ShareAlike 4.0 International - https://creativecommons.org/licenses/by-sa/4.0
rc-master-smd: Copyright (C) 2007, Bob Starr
